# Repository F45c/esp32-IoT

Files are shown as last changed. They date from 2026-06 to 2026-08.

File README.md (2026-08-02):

# Esp32-IoT-Sensors

An Esp32 packed with sensors for IoT use. It uses the Esp32-C3-Mini-1 module that includes an antenna and it receives data from lots of sensors like heart rate, temperature, flame detector and much more.

#### These are the Sensors:

> DHT11
> - Temperature & Humidity
> 
> BMP280
> - Barometer & Air Pressure
> 
> AHT20
> - Temperature & Air Humidity
> 
> MQ-135
> - Air Quality & Gas detection
> 
> MPU-6050
> - Accelerometer & Gyro
> 
> HC-SR501
> - Motion Sensor
> 
> DS18B20
> - Temperature
> 
> MAX30102
> - Heart Rate & Oxigen Saturation
> 
> IR Flame Detector
> 
> Light Dependent Resistor

### Finished Build
I finished the PCB assembly. Since I'm a beginner, I was struggling a lot with the tiny solder joints. The most annoying parts to solder were definitely the BMP280 and the USB-C connector because the pins are so tiny and are easily bridged. Soldering the LEDs failed a few times because I would test them before for polarity check and while picking the up with the tweezers, they would move and I accidentally soldered them wrong a few times.

Originally, I would have unsoldered the MQ-135 gas sensor and solder it to my pcb, but I wasn't able to because of how to module is designed so I stuck the pins that are sticking out of the bottom of the board into my pcb and it fits.

I spaced everything tightly in the design and now that I built it, I find it hard to fully reach the Heart Rate sensor (2nd image bottom right), but since the Motion sensor is unpluggable, you can still use it.

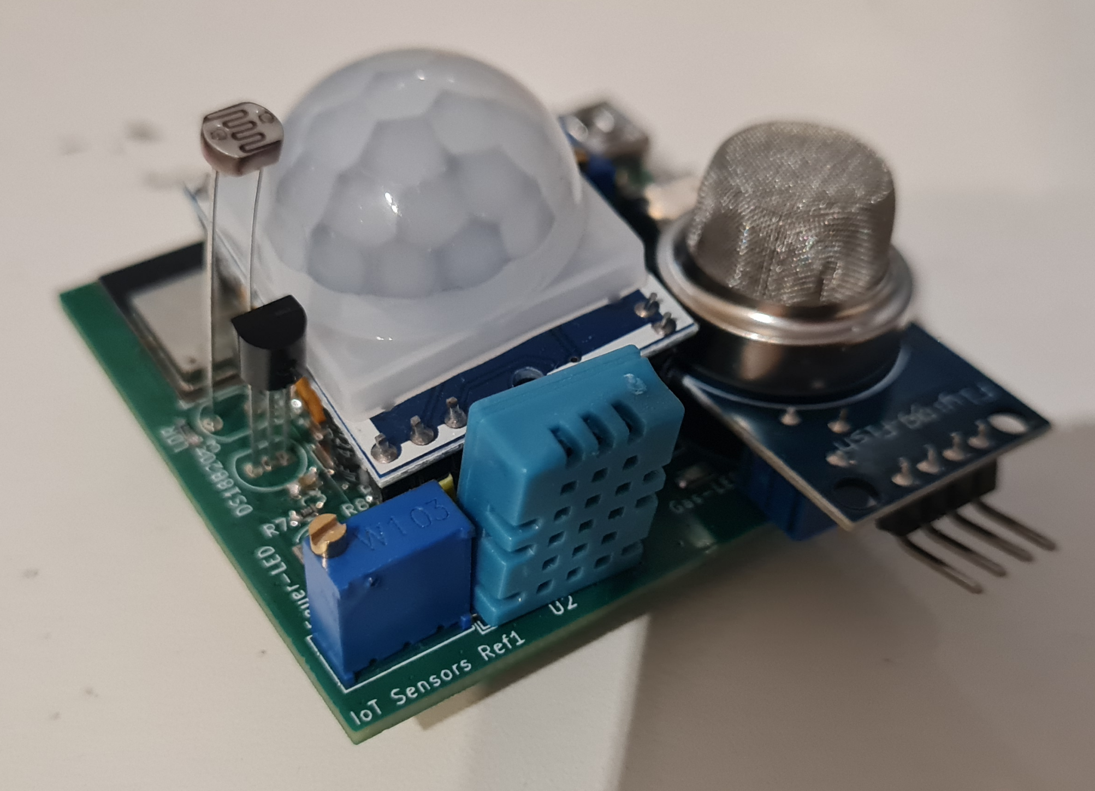
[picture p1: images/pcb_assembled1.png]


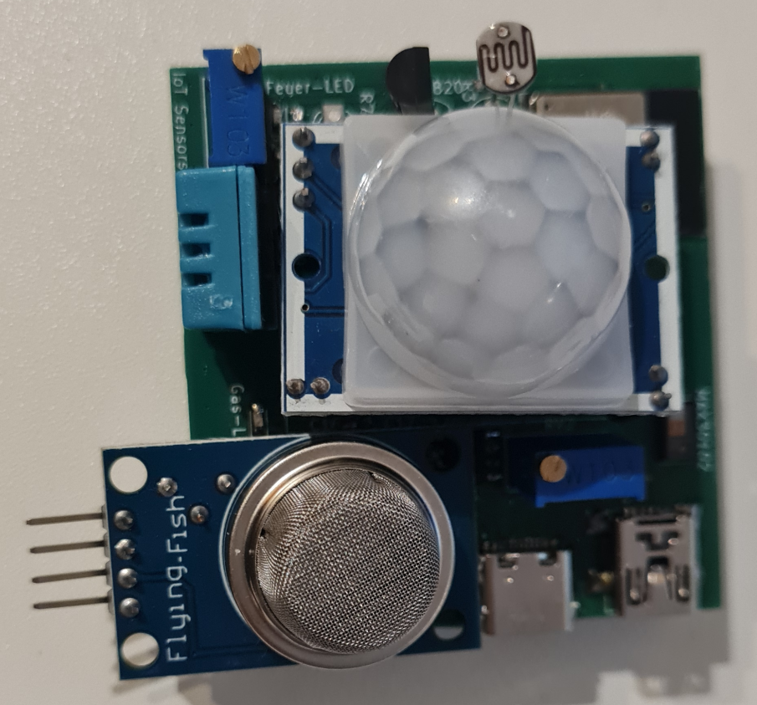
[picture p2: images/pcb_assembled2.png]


Here you can find the Demo Video

## Why am I making this?

I'm building this sensor board for a presentation of mine about Internet of Things.
This will help me demonstrate the practical application of Esp32 Chips, low energy sensors and Telemetry using different Protocols like MQTT. The many different sensors will come in handy when the crowd can try their newly learned skills on programming this device. That's why I designed it very openly and you can clearly see how all the components are connected (when you unplug the motion sensor from the pin sockets)

## Design

I carefully checked that every sensor is in the right place and its functionality won't be blocked by other components (e.g. LDR, IR LED, ...). If you don't like the huge motion detector in the center, you can just unplug it because it's connected via Pin Sockets.

There are two trimmer for controlling the sensitivity of the gas sensor and flame detector respectively.

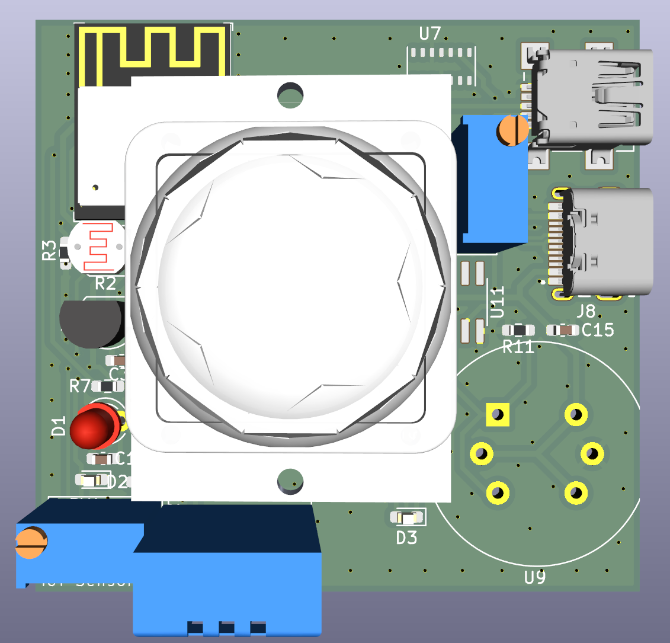
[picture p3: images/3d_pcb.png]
3D Model of PCB


### PCB

The important points to mention in the PCB Design are the two Ground Planes which fill up all unused space on the front and back layers. Though, the space below the esp32's pcb antenna needs to be copper-free allowing the antenna to work without being blocked / the signal reflected.

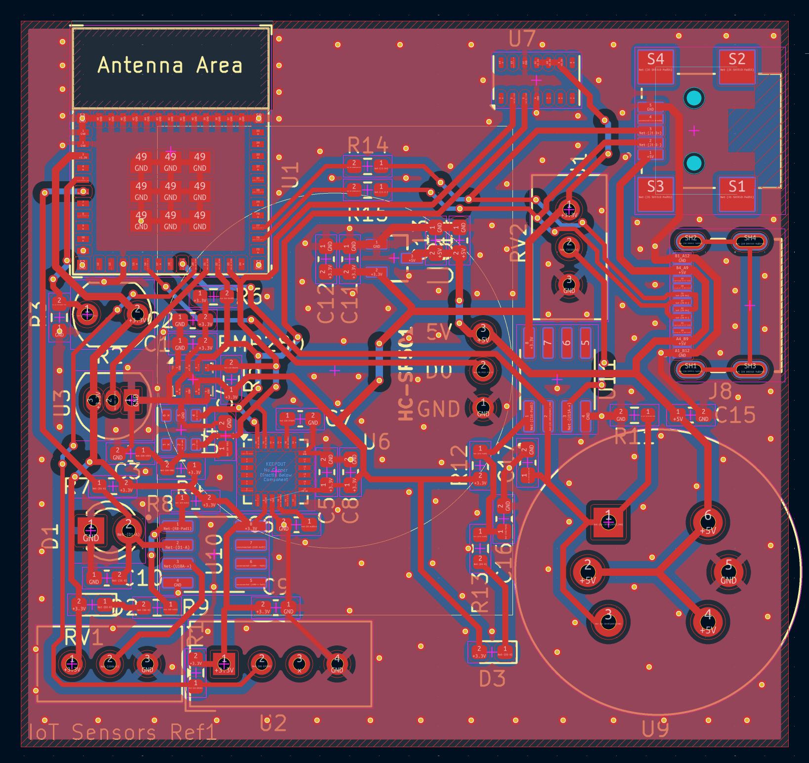
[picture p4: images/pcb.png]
PCB Design


### Schematic

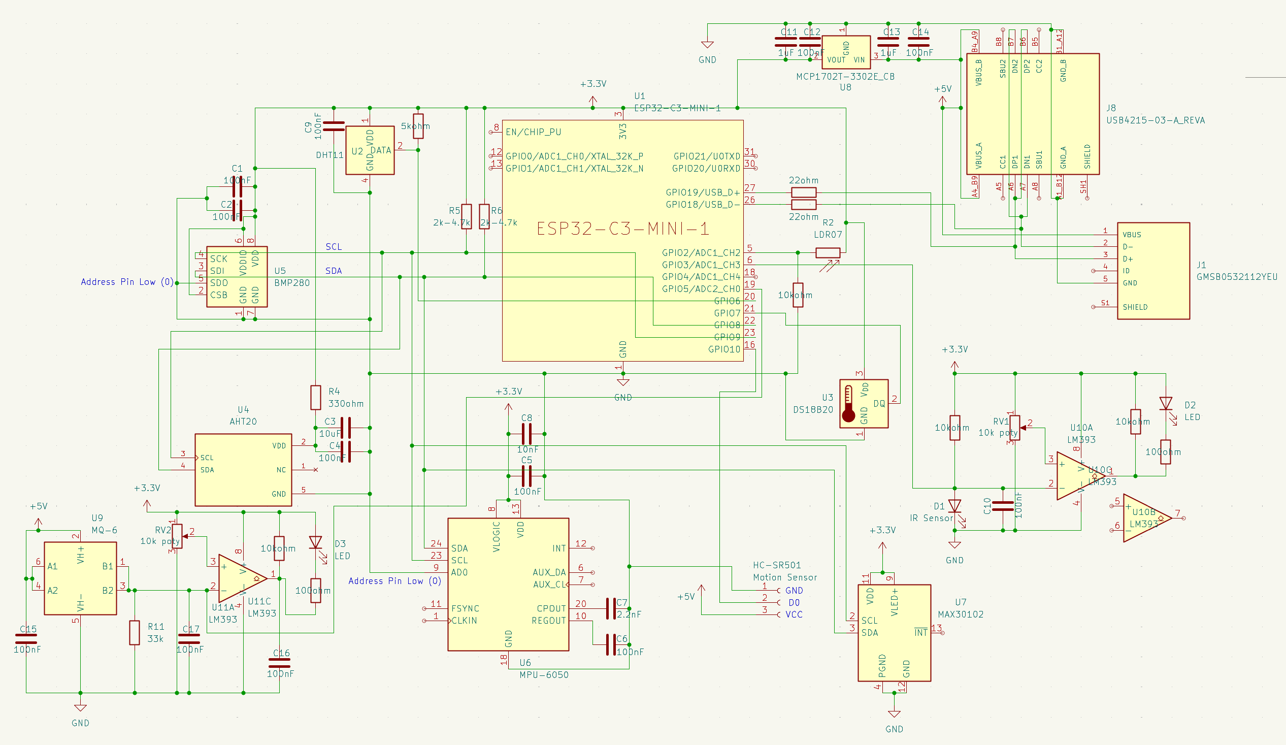
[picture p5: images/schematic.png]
Schematic Design


### BOM
|Name|Purpose|Quantity|Total Cost (USD)|Link|Distributor|
|----|---|---|---|---|---|
|PCB|PCB board|1|5.5||JLCPCB|
|HC-SR501|Motion sensor|1|4.05|https://www.amazon.com/-/de/dp/B09LVJ4DZX|Amazon|
|MQ-135|Gas Sensor|1|4.99|https://www.amazon.com/dp/B0GSRWSLB1|Amazon|
|PCBA|PCB Assembly Parts|1|25.60||JLCPCB|

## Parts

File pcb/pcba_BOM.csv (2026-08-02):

Reference | Qty | Value | DNP | Exclude from BOM | Exclude from Board | Footprint | Datasheet
C1,C2,C4,C5,C6,C9,C10,C12,C14,C15,C16,C17 | 12 | 100nF |  |  |  | Capacitor_SMD:C_0603_1608Metric_Pad1.08x0.95mm_HandSolder
C3 | 1 | 10uF |  |  |  | Capacitor_SMD:C_0603_1608Metric_Pad1.08x0.95mm_HandSolder
C7 | 1 | 2.2nF |  |  |  | Capacitor_SMD:C_0603_1608Metric_Pad1.08x0.95mm_HandSolder
C8 | 1 | 10nF |  |  |  | Capacitor_SMD:C_0603_1608Metric_Pad1.08x0.95mm_HandSolder
C11,C13 | 2 | 1uF |  |  |  | Capacitor_SMD:C_0603_1608Metric_Pad1.08x0.95mm_HandSolder
D1 | 1 | IR Sensor |  |  |  | LED_THT:LED_D3.0mm
D2,D3 | 2 | LED |  |  |  | LED_SMD:LED_0603_1608Metric_Pad1.05x0.95mm_HandSolder
HC-SR501 | 1 | Motion Sensor |  |  |  | HC-SR501-master:HC-SR501
J1 | 1 | GMSB0532112YEU |  |  |  | GMSB0532112YEU:AMPHENOL_GMSB0532112YEU
J8 | 1 | USB4215-03-A_REVA |  |  |  | USB4215-03-A_REVA:GCT_USB4215-03-A_REVA
R1 | 1 | 5kohm |  |  |  | Resistor_SMD:R_0603_1608Metric_Pad0.98x0.95mm_HandSolder
R2 | 1 | LDR07 |  |  |  | OptoDevice:R_LDR_5.1x4.3mm_P3.4mm_Vertical | http://www.tme.eu/de/Document/f2e3ad76a925811312d226c31da4cd7e/LDR07.pdf
R3,R7,R8,R10,R12 | 5 | 10kohm |  |  |  | Resistor_SMD:R_0603_1608Metric_Pad0.98x0.95mm_HandSolder
R4 | 1 | 330ohm |  |  |  | Resistor_SMD:R_0603_1608Metric_Pad0.98x0.95mm_HandSolder
R5,R6 | 2 | 2k-4.7k |  |  |  | Resistor_SMD:R_0603_1608Metric_Pad0.98x0.95mm_HandSolder
R9,R13 | 2 | 100ohm |  |  |  | Resistor_SMD:R_0603_1608Metric_Pad0.98x0.95mm_HandSolder
R11 | 1 | 33k |  |  |  | Resistor_SMD:R_0603_1608Metric_Pad0.98x0.95mm_HandSolder
R14,R15 | 2 | 22ohm |  |  |  | Resistor_SMD:R_0603_1608Metric_Pad0.98x0.95mm_HandSolder
RV1,RV2 | 2 | 10k poty |  |  |  | Potentiometer_THT:Potentiometer_Bourns_3296W_Vertical
U1 | 1 | ESP32-C3-MINI-1 |  |  |  | PCM_Espressif:ESP32-C3-MINI-1 | https://www.espressif.com/sites/default/files/documentation/esp32-c3-mini-1_datasheet_en.pdf
U2 | 1 | DHT11 |  |  |  | Sensor:Aosong_DHT11_5.5x12.0_P2.54mm | http://akizukidenshi.com/download/ds/aosong/DHT11.pdf
U3 | 1 | DS18B20 |  |  |  | Package_TO_SOT_THT:TO-92_Inline | http://datasheets.maximintegrated.com/en/ds/DS18B20.pdf
U4 | 1 | AHT20 |  |  |  | AHT20:PSON100P300X300X110-6N
U5 | 1 | BMP280 |  |  |  | Package_LGA:Bosch_LGA-8_2x2.5mm_P0.65mm_ClockwisePinNumbering | https://ae-bst.resource.bosch.com/media/_tech/media/datasheets/BST-BMP280-DS001.pdf
U6 | 1 | MPU-6050 |  |  |  | Sensor_Motion:InvenSense_QFN-24_4x4mm_P0.5mm | https://invensense.tdk.com/wp-content/uploads/2015/02/MPU-6000-Datasheet1.pdf
U7 | 1 | MAX30102 |  |  |  | OptoDevice:Maxim_OLGA-14_3.3x5.6mm_P0.8mm | https://datasheets.maximintegrated.com/en/ds/MAX30102.pdf
U8 | 1 | MCP1702T-3302E_CB |  |  |  | MCP1702T-3302E_CB:SOT95P255X145-3N
U9 | 1 | MQ-6 |  |  |  | Sensor:MQ-6 | https://www.winsen-sensor.com/d/files/semiconductor/mq-6.pdf
U10,U11 | 2 | LM393 |  |  |  | LM393DR2G:SOIC127P600X265-8N | http://www.ti.com/lit/ds/symlink/lm393.pdf
U11 | 1 | LM393 |  |  |  | LM393DR2G:SOIC127P600X265-8N | http://www.ti.com/lit/ds/symlink/lm393.pdf

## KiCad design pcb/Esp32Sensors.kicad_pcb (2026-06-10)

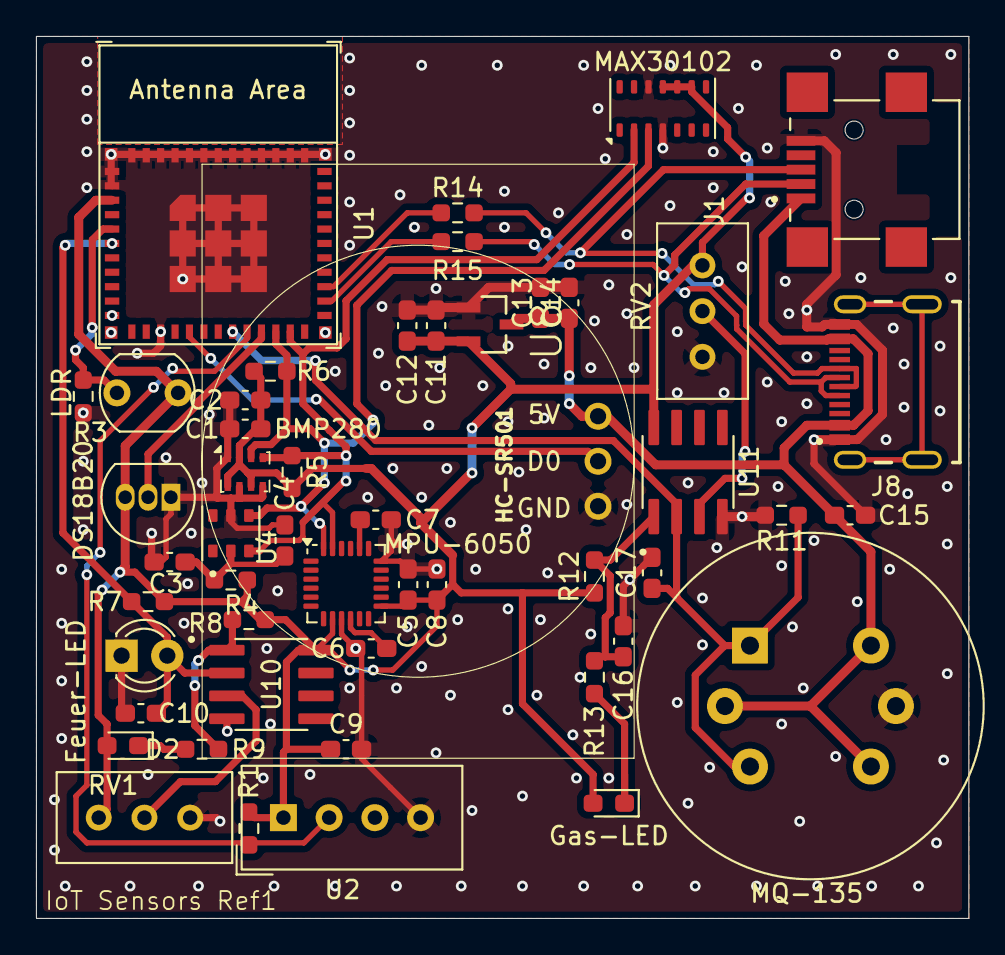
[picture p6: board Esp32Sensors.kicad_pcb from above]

Board: 2 copper layers, 51.8 x 49.0 mm, 50 parts (0 on the bottom side), 26 nets.

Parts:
C1, C2, C4, C5, C6, C9, C10, C12, C14, C15, C16, C17: 100nF; C_0603_1608Metric_Pad1.08x0.95mm_HandSolder
C3: 10uF; C_0603_1608Metric_Pad1.08x0.95mm_HandSolder
C7: 2.2nF; C_0603_1608Metric_Pad1.08x0.95mm_HandSolder
C8: 10nF; C_0603_1608Metric_Pad1.08x0.95mm_HandSolder
C11, C13: 1uF; C_0603_1608Metric_Pad1.08x0.95mm_HandSolder
D2: LED; LED_0603_1608Metric_Pad1.05x0.95mm_HandSolder
DS18B20: DS18B20; TO-92_Inline
Feuer-LED: IR Sensor; LED_D3.0mm
Gas-LED: LED; LED_0603_1608Metric_Pad1.05x0.95mm_HandSolder
HC-SR501: Motion Sensor; HC-SR501
J1: GMSB0532112YEU; AMPHENOL_GMSB0532112YEU
J8: USB4215-03-A_REVA; GCT_USB4215-03-A_REVA
LDR: LDR07; R_LDR_5.1x4.3mm_P3.4mm_Vertical
MAX30102: MAX30102; Maxim_OLGA-14_3.3x5.6mm_P0.8mm
MPU-6050: MPU-6050; InvenSense_QFN-24_4x4mm_P0.5mm
MQ-135: MQ-6
R1: 5kohm; R_0603_1608Metric_Pad0.98x0.95mm_HandSolder
R3, R7, R8, R12: 10kohm; R_0603_1608Metric_Pad0.98x0.95mm_HandSolder
R4: 330ohm; R_0603_1608Metric_Pad0.98x0.95mm_HandSolder
R5, R6: 2k-4.7k; R_0603_1608Metric_Pad0.98x0.95mm_HandSolder
R9, R13: 100ohm; R_0603_1608Metric_Pad0.98x0.95mm_HandSolder
R11: 33k; R_0603_1608Metric_Pad0.98x0.95mm_HandSolder
R14, R15: 22ohm; R_0603_1608Metric_Pad0.98x0.95mm_HandSolder
RV1, RV2: 10k poty; Potentiometer_Bourns_3296W_Vertical
U1: ESP32-C3-MINI-1
U2: DHT11; Aosong_DHT11_5.5x12.0_P2.54mm
U4: AHT20; PSON100P300X300X110-6N
U5: BMP280; Bosch_LGA-8_2x2.5mm_P0.65mm_ClockwisePinNumbering
U8: MCP1702T-3302E_CB; SOT95P255X145-3N
U10, U11: LM393; SOIC127P600X265-8N

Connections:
+3.3V: C1.2, C2.2, C5.1, C8.1, C9.2, C11.2, C12.2, D2.2 (A), DS18B20.3 (V_{DD}), Gas-LED.2 (A), LDR.2, MAX30102.9 (VLED+), MAX30102.10 (VLED+), MAX30102.11 (VDD), MPU-6050.8 (VLOGIC), MPU-6050.13 (VDD), R1.2, R4.1, R5.1, R6.1, R7.2, R8.2, R12.2, RV1.1, RV2.1, U1.3 (3V3), U2.1 (VDD), U5.2 (CSB), U5.6 (VDDIO), U5.8 (VDD), U8.2 (VOUT), U10.8 (V+), U11.8 (V+)
+5V: C13.2, C14.2, C15.1, HC-SR501.3, J1.1 (VBUS), J8.A4_B9 (VBUS_A), J8.B4_A9 (VBUS_B), MQ-135.2 (VH+), MQ-135.4 (A2), MQ-135.6 (A1), U8.3 (VIN)
GND: C1.1, C2.1, C3.2, C4.2, C5.2, C6.2, C7.2, C8.2, C9.1, C10.1, C11.1, C12.1, C13.1, C14.1, C15.2, C16.2, C17.2, DS18B20.1 (GND), Feuer-LED.1 (K), HC-SR501.1, J1.5 (GND), J8.A1_B12 (GND_A), J8.B1_A12 (GND_B), MAX30102.4 (PGND), MAX30102.12 (GND), MPU-6050.9 (AD0), MPU-6050.18 (GND), MQ-135.5 (VH-), R3.1, R11.2, RV1.3, RV2.3, U1.1 (GND), U1.2 (GND), U1.11 (GND), U1.14 (GND), U1.36 (GND), U1.37 (GND), U1.38 (GND), U1.39 (GND), U1.40 (GND), U1.41 (GND), U1.42 (GND), U1.43 (GND), U1.44 (GND), U1.45 (GND), U1.46 (GND), U1.47 (GND), U1.48 (GND), U1.49 (GND), U1.50 (GND), U1.51 (GND), U1.52 (GND), U1.53 (GND), U2.4 (GND), U4.5 (GND), U5.1 (GND), U5.5 (SDO), U5.7 (GND), U8.1 (GND), U10.4 (V-), U11.4 (V-)
unnamed: C16.1, R12.1, R13.1, U11.1
unnamed: C10.2, Feuer-LED.2 (A), R7.1, U1.6 (GPIO3/ADC1_CH3), U10.2 (-)
unnamed: D2.1 (K), R9.2
unnamed: Gas-LED.1 (K), R13.2
unnamed: HC-SR501.2, U1.16 (GPIO10)
unnamed: J1.3 (D+), J8.A6 (DP1), J8.B6 (DP2), R14.1
unnamed: J1.2 (D-), J8.A7 (DN1), J8.B7 (DN2), R15.1
unnamed: J1.S1 (SHIELD), J1.S2 (SHIELD), J1.S3 (SHIELD), J1.S4 (SHIELD)
unnamed: J8.SH1 (SHIELD), J8.SH2 (SHIELD), J8.SH3 (SHIELD), J8.SH4 (SHIELD)
unnamed: R8.1, R9.1, U10.1
unnamed: LDR.1, R3.2, U1.5 (GPIO2/ADC1_CH2)
unnamed: C17.1, MQ-135.1 (B1), MQ-135.3 (B2), R11.1, U1.19 (GPIO5/ADC2_CH0), U11.2 (-)
unnamed: R1.1, U1.20 (GPIO6), U2.2 (DATA)
unnamed: DS18B20.2 (DQ), U1.21 (GPIO7)
unnamed: MAX30102.3 (SDA), MPU-6050.24 (SDA), R6.2, U1.22 (GPIO8), U4.4 (SDA), U5.3 (SDI)
unnamed: MAX30102.2 (SCL), MPU-6050.23 (SCL), R5.2, U1.23 (GPIO9), U4.3 (SCL), U5.4 (SCK)
unnamed: R15.2, U1.26 (GPIO18/USB_D-)
unnamed: R14.2, U1.27 (GPIO19/USB_D+)
unnamed: C3.1, C4.1, R4.2, U4.2 (VDD)
unnamed: C7.1, MPU-6050.20 (CPOUT)
unnamed: C6.1, MPU-6050.10 (REGOUT)
unnamed: RV1.2, U10.3 (+)
unnamed: RV2.2, U11.3 (+)

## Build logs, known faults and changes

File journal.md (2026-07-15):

# Soldering the PCB

_Time Spent: 1.5h_

I started with the USB connectors because they were the toughest to solder because of the tiny pins. For the Micro USB Type B, I used a normal soldering iron and it worked all right since the pins are bigger than from the USB C. That's why I used a hot air gun with solder paste for this one and had to fix a few bridging pins and because I already have some experience soldering the USB-C connector from another project, it worked a little faster this time.

After that, I tried soldering the Esp32 C3 Mini 1 module with a heat gun and solder paste which I re-did multiple times because I was never sure that all pins are really connected to their pads. This was definitely one of the difficult parts on the PCB.

Then, I made my way over to the smaller components.

Starting with the BMP280 sensor which was difficult to solder. The chip itself is so tiny, I couldn't see if the pins were connected. The AHT20 and MAX30102 went a little better since they're bigger. All the other components also didn't hold me back a lot, for the LEDs, I just had to check polarity and solder them in the right way. Since I couldn't unsolder the gas sensor from its module, I just plugged it in like that and it should work the same because all the pins are still correct. At the end, I supplied the board with power and measured the capacitors and checked the LEDs and everything worked!



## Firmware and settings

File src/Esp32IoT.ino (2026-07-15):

#include <SPI.h>
#include <Wire.h>
#include <Adafruit_BMP280.h>
#include <AHT20.h>
#include <DHT11.h>
#include <DallasTemperature.h>
#include <Adafruit_MPU6050.h>
#include <Adafruit_Sensor.h>
#include "DevLab_MAX30102.h"
#include "heartRate.h"

#define BMP_SCK 13
#define BMP_MISO 12
#define BMP_MOSI 11
#define BMP_CS 10
#define DS18B20 7

AHT20 aht20;
Adafruit_BMP280 bmp;
DHT11 dht11(6);
OneWire oneWire(DS18B20);
DallasTemperature sensors(&oneWire);
Adafruit_MPU6050 mpu;
DevLab_MAX30102 particleSensor;

const byte RATE_SIZE = 4;
byte rates[RATE_SIZE];
byte rateSpot = 0;
long lastBeat = 0;
float beatsPerMinute;
int beatAvg;

void setup() {
  unsigned status;
  status = bmp.begin();

  if (!status) Serial.println("BMP280 not connected correctly");

  bmp.setSampling(Adafruit_BMP280::MODE_NORMAL,
                  Adafruit_BMP280::SAMPLING_X2,
                  Adafruit_BMP280::SAMPLING_X16,
                  Adafruit_BMP280::FILTER_X16,
                  Adafruit_BMP280::STANDBY_MS_500);

  Wire.begin();
  if (aht20.begin() == false) Serial.println("AHT20 not connected correctly");

  sensors.begin();

  if (!mpu.begin()) Serial.println("MPU6050 not connected correctly");

  mpu.setAccelerometerRange(MPU6050_RANGE_4_G);
  mpu.setGyroRange(MPU6050_RANGE_500_DEG);
  mpu.setFilterBandwidth(MPU6050_BAND_21_HZ);


  if (!particleSensor.begin(Wire, I2C_SPEED_FAST)) Serial.println("MAX30102 not connected correctly");

  particleSensor.setup();
  particleSensor.setPulseAmplitudeRed(0x0A);
  particleSensor.setPulseAmplitudeGreen(0);
}

void measureHeartRate() {
  long irValue = particleSensor.getIR();

  if (checkForBeat(irValue) == true)
  {
    long delta = millis() - lastBeat;
    lastBeat = millis();

    beatsPerMinute = 60 / (delta / 1000.0);

    if (beatsPerMinute < 255 && beatsPerMinute > 20)
    {
      rates[rateSpot++] = (byte)beatsPerMinute;
      rateSpot %= RATE_SIZE;

      beatAvg = 0;
      for (byte x = 0 ; x < RATE_SIZE ; x++)
        beatAvg += rates[x];
      beatAvg /= RATE_SIZE;
    }
  }

  Serial.print("IR=");
  Serial.print(irValue);
  Serial.print(", BPM=");
  Serial.print(beatsPerMinute);
  Serial.print(", Avg BPM=");
  Serial.print(beatAvg);

  if (irValue < 50000)
    Serial.print(" No finger?");

  Serial.println();
}

void loop() {
  Serial.println("BMP280");
  Serial.print(F("Temperature = "));
  Serial.print(bmp.readTemperature());
  Serial.println(" *C");

  Serial.print(F("Pressure = "));
  Serial.print(bmp.readPressure());
  Serial.println(" Pa");

  Serial.print(F("Approx altitude = "));
  Serial.print(bmp.readAltitude(1013.25));
  Serial.println(" m");



  Serial.println("AHT20");
  Serial.print("T: ");
  Serial.print(aht20.getTemperature(), 2);
  Serial.print(" C\t H: ");
  Serial.print(aht20.getHumidity(), 2);
  Serial.println("% RH");


  int temperature = 0;
  int humidity = 0;
  int result = dht11.readTemperatureHumidity(temperature, humidity);

  if (result == 0) {
    Serial.print("Temperature: ");
    Serial.print(temperature);
    Serial.print(" °C\tHumidity: ");
    Serial.print(humidity);
    Serial.println(" %");
  } else Serial.println(DHT11::getErrorString(result));

  sensors.requestTemperatures();
  Serial.print("DS18B20: ");
  Serial.print(sensors.getTempCByIndex(0));
  Serial.println(" °C");

  Serial.print("LDR reading: ");
  Serial.println(analogRead(2));

  Serial.print("IR Flame Detector reading: ");
  Serial.println(analogRead(3));

  Serial.print("Gas Sensor reading: ");
  Serial.println(analogRead(5));


  sensors_event_t a, g, temp;
  mpu.getEvent(&a, &g, &temp);

  Serial.print("Acceleration X: ");
  Serial.print(a.acceleration.x);
  Serial.print(", Y: ");
  Serial.print(a.acceleration.y);
  Serial.print(", Z: ");
  Serial.print(a.acceleration.z);
  Serial.println(" m/s^2");

  Serial.print("Rotation X: ");
  Serial.print(g.gyro.x);
  Serial.print(", Y: ");
  Serial.print(g.gyro.y);
  Serial.print(", Z: ");
  Serial.print(g.gyro.z);
  Serial.println(" rad/s");

  Serial.print("Temperature: ");
  Serial.print(temp.temperature);
  Serial.println(" degC");


  Serial.print(" R[");
  Serial.print(particleSensor.getRed());
  Serial.print("] IR[");
  Serial.print(particleSensor.getIR());
  Serial.print("] G[");
  Serial.print(particleSensor.getGreen());
  Serial.println("]");


}

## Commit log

2026-06-08 added pcb files
    [Esp32Sensors.kicad_pcb, Esp32Sensors.kicad_sch]
2026-06-08 updated pcb files
    [Esp32Sensors.kicad_pcb, Esp32Sensors.kicad_sch]
2026-06-10 updated schematic image
2026-06-12 added bom.csv
    [bom.csv]
2026-06-12 added bom to readme
2026-08-01 fixed bom
    [bom.csv]
2026-08-02 added pcba bom
    [pcba_BOM.csv]
2026-08-02 changed bom.csv
    [bom.csv]
2026-08-02 added pcba to bom
    [bom.csv]
2026-08-02 added pcba to bom in readme
